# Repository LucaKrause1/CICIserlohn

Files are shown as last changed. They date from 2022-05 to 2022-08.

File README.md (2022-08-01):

# CICIserlohn
Dieses Projekt ist im Zuge der Cross Innovation Class 2022 in der Zusammenarbeit dreier Hochschulen (Fachhochschule Wedel, Akademie für Mode und Design, HafenCity-Universität) und der Kreativgesellschaft Hamburg entstanden. Dabei soll am Ende der Arbeitszeit ein Prototyp entstehen.

Fragestellung: Wie lässt sich das Thema SMART CITY für die Stadtgesellschaft im Wald
| Stadt | Labor Iserlohn erlebbar und greifbar gestalten (z.B. Smart
Gadgets, Sensorik)?

Als Lösung dieser Fragestellung haben wir uns für ein interaktives Stadtmodell entschieden, was, im Gegensatz zu vielen anderen Stadtmodellen auf dem Tisch, an der Wand hängt. Auf dieses Stadtmodell werden Strukturen mit einem Beamer projiziert. Der Nutzer des Modells kann durch verschiedene, mit NFC-Tags versehene, Objekte an einen RFID-Reader halten und dadurch eine Änderung der Strukturen auf dem projizierten Stadtplan hervorrufen.

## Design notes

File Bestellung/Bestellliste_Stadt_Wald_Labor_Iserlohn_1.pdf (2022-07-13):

Bestellliste Stadt Wald Labor Iserlohn 1 | 1

🛒

# Bestellliste Stadt Wald Labor Iserlohn 1

Kosten

Name | Anzahl | Link | Preis pro Stück | Preis
Spule (https://www.notion.so/Spule-8c49362c32854b4bae962a846aa26daf) | 3 | https://www.mouser.de/ProductDetail/Seeed-Studio/106990017?qs=SElPoaY2y5KdLskE1shzqQ%3D%3D | €7.70 | 23.1
Plexiglasröhre 25cm (https://www.notion.so/Plexiglasr-hre-25cm-c4fa1f32a551414896a60412c5162a9e) | 3 | https://www.plattenzuschnitt24.de/Plexiglas-XT-Rohr-3mm-farblos-150-144.html | €15.50 | 46.5
NodeMCU (https://www.notion.so/NodeMCU-fe49acd63b5244f4bf1ca105369e4d74) | 4 | https://www.mouser.de/ProductDetail/Espressif-Systems/ESP32-S2-DevKitM-1?qs=DPoM0jnrROXzO8seOHN%252BOQ%3D%3D (https://www.mouser.de/ProductDetail/Espressif-Systems/ESP32-DevKitC-32E?qs=GedFDFLaBXFpgD0kAZWDrQ%3D%3D) | €9.50 | 38
NFC Reader (https://www.notion.so/NFC-Reader-c93f7a633db04cc8bf8a1b0f69995adc) | 2 | https://www.reichelt.de/entwicklerboards-rfid-modul-nxp-mfrc-522-debo-rfid-rc522-p192147.html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 (https://www.reichelt.de/entwicklerboards-rfid-modul-nxp-mfrc-522-debo-rfid-rc522-p192147.html?PROVID=2788) | €10.40 | 20.8
NFC Tags 10 Stück (https://www.notion.so/NFC-Tags-10-St-ck-2ceb18d98208488e8c25912d936efacc) | 2 | https://www.reichelt.de/rfid-nfc-tags-weiss-10-stueck-berrybase-125450-p313935.html?&trstct=pos_1&nbc=1 (https://www.reichelt.de/rfid-nfc-tags-weiss-10-stueck-berrybase-125450-p313935.html?trstct=pos_1&nbc=1) | €4.60 | 9.2
Filament (https://www.notion.so/Filament-1f2108d9e0b64ece85e25cef391650d0) | 3 | https://www.voelkner.de/products/5806131/Polymaker-70822-PolyTerra-PLA-Filament-PLA-1.75mm-1000g-Weiss-matt-1St..html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 (https://www.voelkner.de/products/5806131/Polymaker-70822-PolyTerra-PLA-Filament-PLA-1.75mm-1000g-Weiss-matt-1St..html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) | €18.90 | 56.7
RaspberryPi (https://www.notion.so/RaspberryPi-6e558a5876fe4d249c60e1b989ea91c8) | 1 | Liegt noch bei dir im Schrank, haben wir letzte Woche drüber geredet | €40.00 | 40
Netzteil (https://www.notion.so/Netzteil-4e05ee1355684bcc99b098a08b8a524c) | 2 | Sollten da auch noch liegen, ansonsten: https://www.reichelt.de/raspberry-pi-netzteil-5-v-2-5-a-micro-usb-schwarz-rasp-nt-25-sw-e-p240934.html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 (https://www.reichelt.de/raspberry-pi-netzteil-5-v-2-5-a-micro-usb-schwarz-rasp-nt-25-sw-e-p240934.html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) | €7.50 | 15
Arcyglaskleber (https://www.notion.so/Arcyglaskleber-7d73b51099e449c5a3fcde43be2412e9) | 1 | https://www.plattenzuschnitt24.de/Acrifix-1R-0192.html | €9.95 | 9.95
LED’s für Baum (https://www.notion.so/LED-s-f-r-Baum-455b00d39e2946deaf79b7cb2db5692d) | 1 | Eigenbestand | €0.00 | 0
Tisch (https://www.notion.so/Tisch-fe3373356d144a98b01e86cf9ac5e2ae) | 1 | | | 0
Base Platte (https://www.notion.so/Base-Platte-695419f74f984da3b0bfcccdbd136a6d) | 1 | | | 0
Beamer (https://www.notion.so/Beamer-f45384da50f442048f5b623bb365f23a) | 0 | https://www.amazon.de/Viewsonic-PA503W-Projektor-Lautsprecher-optischer/dp/B0749NTSCD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 (https://www.amazon.de/Viewsonic-PA503W-Projektor-Lautsprecher-optischer/dp/B0749NTSCD) | €420.00 | 0

Zu den Plexiglasröhren, die Konfiguration sollte so aussehen:

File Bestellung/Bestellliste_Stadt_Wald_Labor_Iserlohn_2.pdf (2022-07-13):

Bestellliste Stadt Wald Labor Iserlohn 2 | 1

🛒

# Bestellliste Stadt Wald Labor Iserlohn 2

Kosten

Name | Anzahl | Link | Preis pro Stück | Preis
Motor (https://www.notion.so/Motor-e24402504231499a8e0da62e9109d887) | 2 | https://www.reichelt.de/entwicklerboards-schrittmotor-inkl-steuerung-uln2003-debo-moto1-p192146.html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 | €5.70 | 11.4
Füße (https://www.notion.so/F-e-257c479b30d344558789728a389d7ed5) | 1

https://www.heimwerkertools.com/moebelbeschlaege/tischbeschlaege/moebelfuessesockelversteller/sockelverstellfuesse/1290/haefele-sockelhoehenversteller-h3930-mit-aufl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 im Endeffekt andere gekauft über Amazon (beinhaltet 4 Füße): (https://www.heimwerkertools.com/moebelbeschlaege/tischbeschlaege/moebelfuesse-sockelversteller/sockelverstellfuesse/1290/haefele-sockelhoehenversteller-h3930-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) https://www.amazon.de/gp/product/B093B3973T/ref=ppx_yo_dt_b_asin_title_o02_s00?ie=UTF8&psc=1

€13.99 | 13.99
SD Karte (https://www.notion.so/SD-Karte-cf0688252be1498da346c247a6cb7903) | 1 | https://www.reichelt.de/microsdhc-speicherkarte-32gb-intenso-class-10-intenso-3413480-p126588.html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 | €5.70 | 5.7

WS2812B 5m

60LEDs/m (https://www.notion.so/WS2812B-5m-60LEDs-m-0d3e1547b6a649f0a9cc99549b60259d) | 1 | https://www.amazon.de/BTF-LIGHTING-WS2812B-300LEDs-Streifen-NichtWasserdicht/dp/B01CDTEJBG/ref=sr_1_6?
| | __mk_de_DE=ÅMÅŽÕÑ&crid=2L99UUTMSW625&keywords=ws2812b&qid=1655209381&sprefix=ws2812b%2Caps%2C107&sr=8-
| | 6 (https://www.amazon.de/BTF-LIGHTING-WS2812B-300LEDs-Streifen-NichtWasserdicht/dp/B01CDTEJBG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) | €41.00 | 41
Netzteil (https://www.notion.so/Netzteil-4e56c5377cda423f8385280d2461815e) | 1 | https://www.reichelt.de/raspberry-pi-netzteil-5-v-2-5-a-micro-usb-schwarz-rasp-nt-25-sw-e-p240934.html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 | €7.50 | 7.5
Motortreiber (https://www.notion.so/Motortreiber-ba87cd8ae5044f4c86f9915cef0a768e) | 3 | https://www.reichelt.de/motortreiber-4-fach-dip-16-l-293-d-ne-p233017.html?&trstct=pos_6&nbc=1 | €3.70 | 11.1
Vibrationsmotoren (https://www.notion.so/Vibrationsmotoren-a66a914f99cd46ddbb9535f4298cdd53) | 3 | https://www.reichelt.de/vibrationsmotor-3-v-150-ma-10-000-u-min-vm-0610-a-3-0-p152129.html?&trstct=pos_0&nbc=1 | €2.20 | 6.6
HDMI Kabel (https://www.notion.so/HDMI-Kabel-cd910cb0324e4462939e0792ff2bdef0) | 1 | https://www.reichelt.de/high-retention-hdmi-kabel-2-0m-hdmi-mmr-2-0muf-p287016.html?&trstct=pos_9&nbc=1 | €7.00 | 7

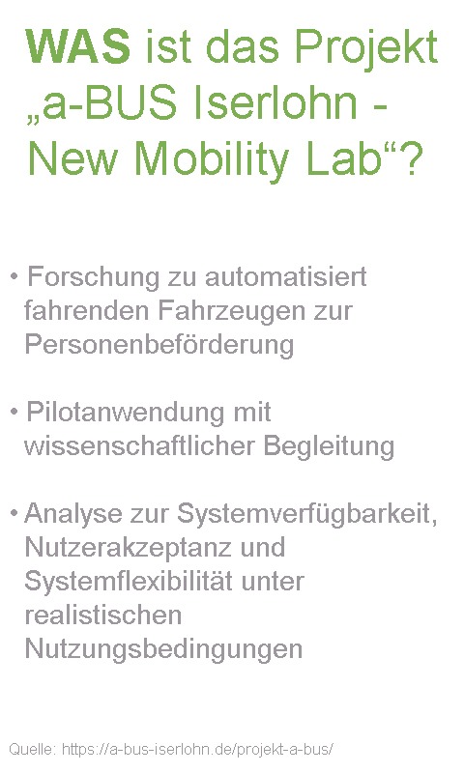
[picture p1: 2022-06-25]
PiScripts/Projection/img/infoabus0.jpg

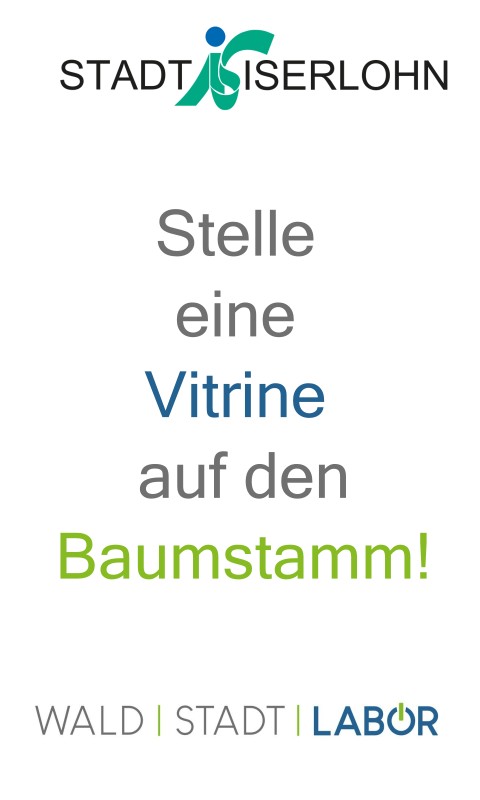
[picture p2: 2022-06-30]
PiScripts/Projection/img/info0.jpg

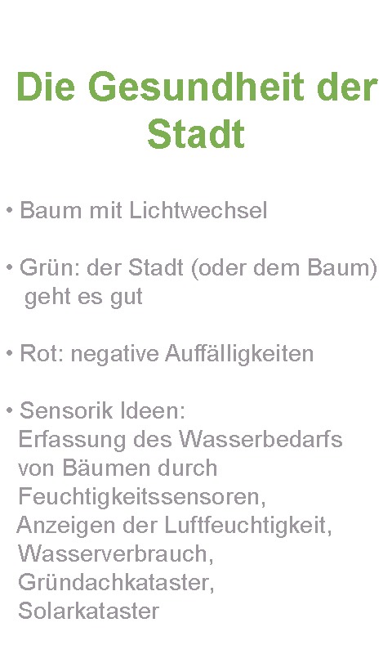
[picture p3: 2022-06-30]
PiScripts/Projection/img/infoTree3.jpg

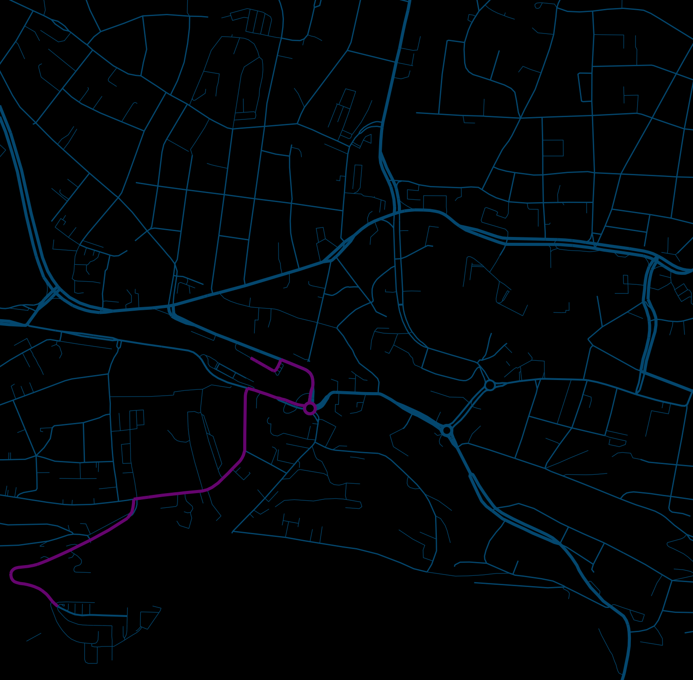
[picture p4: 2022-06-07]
PiScripts/Projection/img/greyBus.png

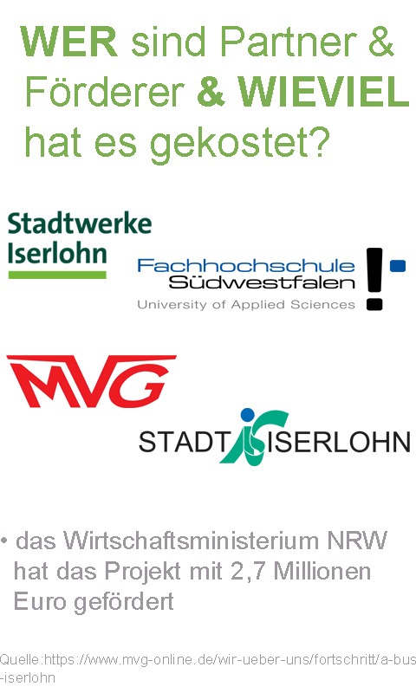
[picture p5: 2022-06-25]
PiScripts/Projection/img/infoabus2.jpg

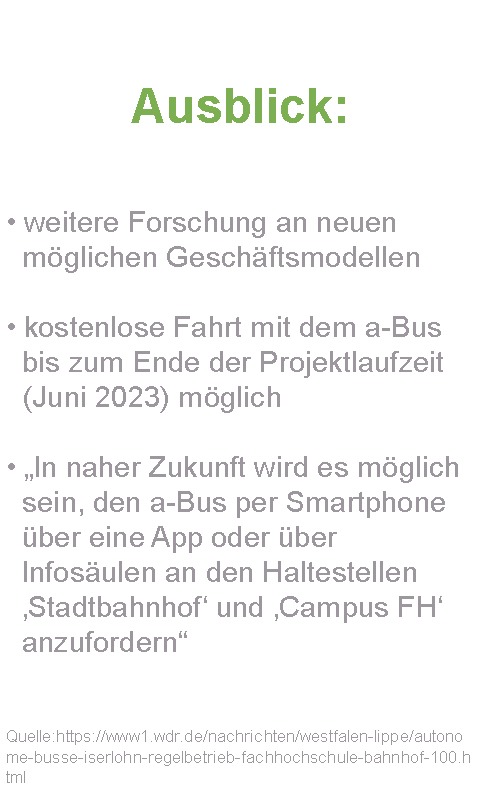
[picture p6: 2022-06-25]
PiScripts/Projection/img/infoabus3.jpg

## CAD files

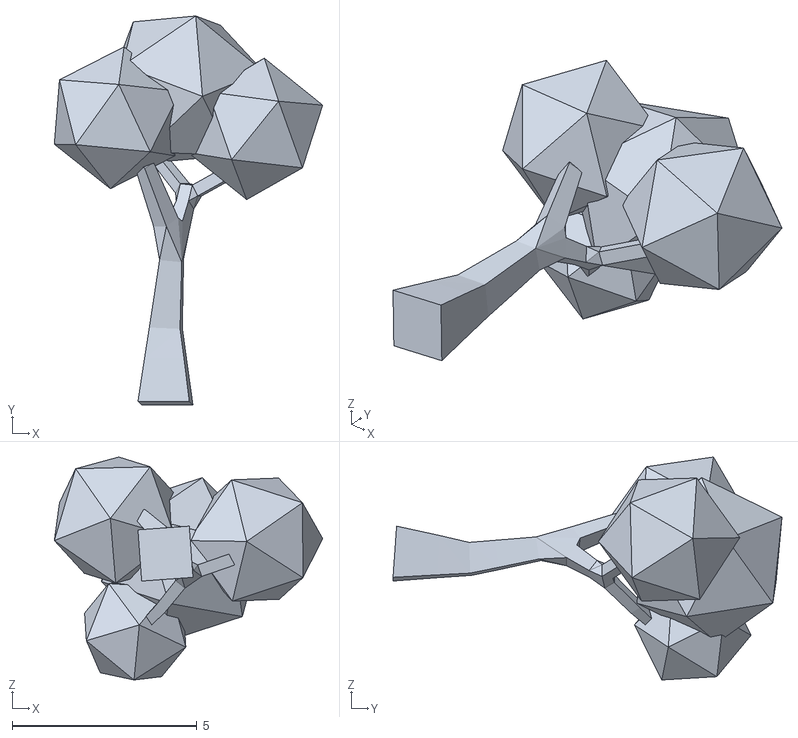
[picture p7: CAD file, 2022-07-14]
3D-Komponenten/Baumv4.obj
7.27 x 10.5 x 6.04

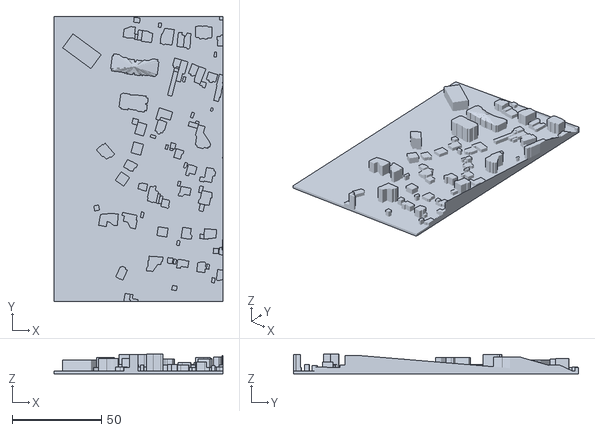
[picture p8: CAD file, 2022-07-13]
3D-Komponenten/Stadtmodell/20.obj
94.9 x 160.0 x 11.0

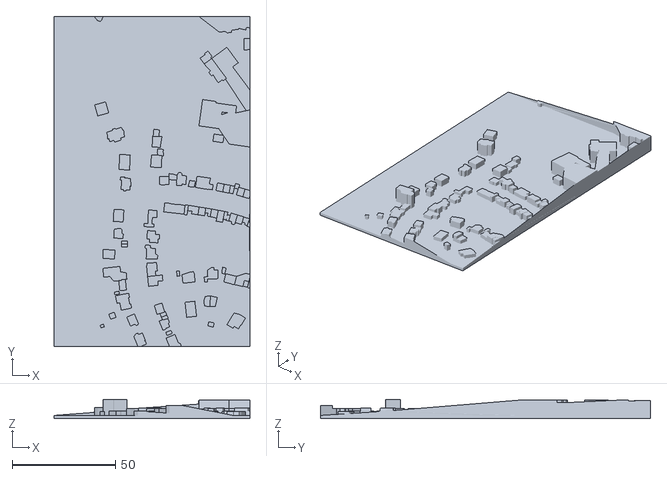
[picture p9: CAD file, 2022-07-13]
3D-Komponenten/Stadtmodell/10.obj
95.0 x 160.1 x 9.40

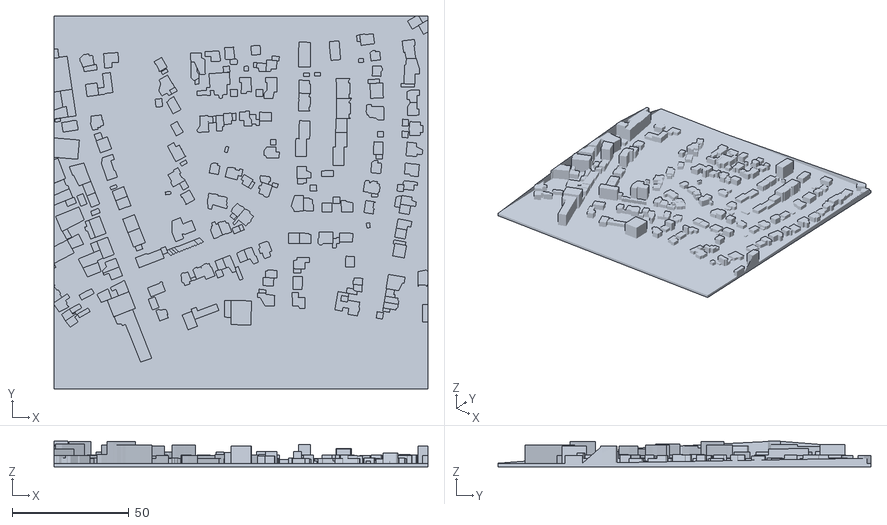
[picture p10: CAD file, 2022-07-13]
3D-Komponenten/Stadtmodell/2.obj
160.1 x 159.5 x 11.1

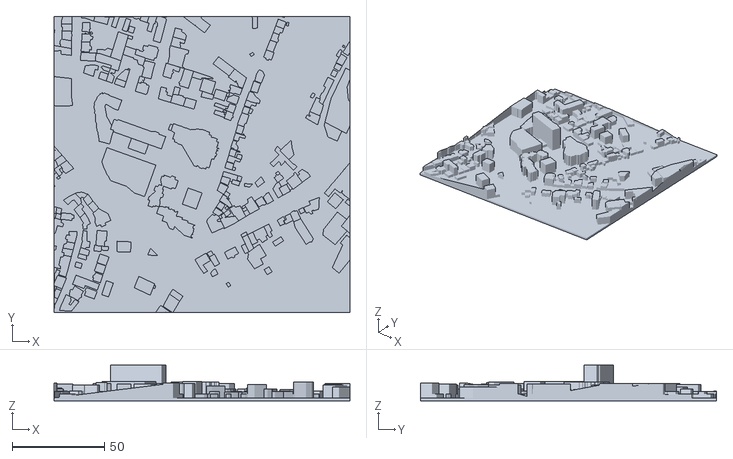
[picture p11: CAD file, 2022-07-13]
3D-Komponenten/Stadtmodell/17.obj
160.1 x 160.1 x 19.3

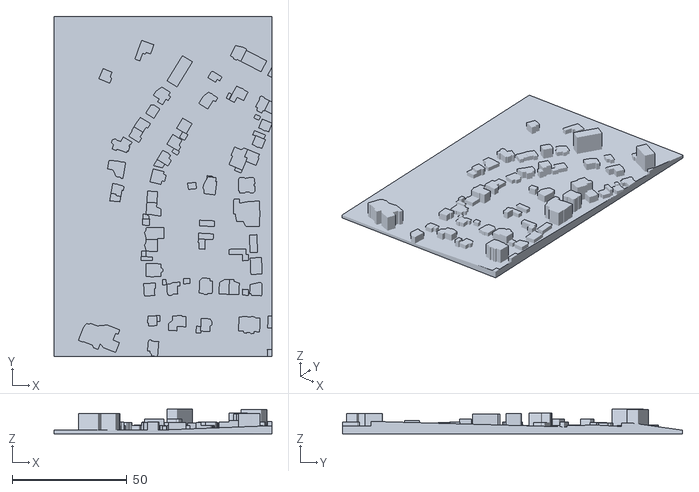
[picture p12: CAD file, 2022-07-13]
3D-Komponenten/Stadtmodell/25.obj
94.9 x 148.1 x 10.7

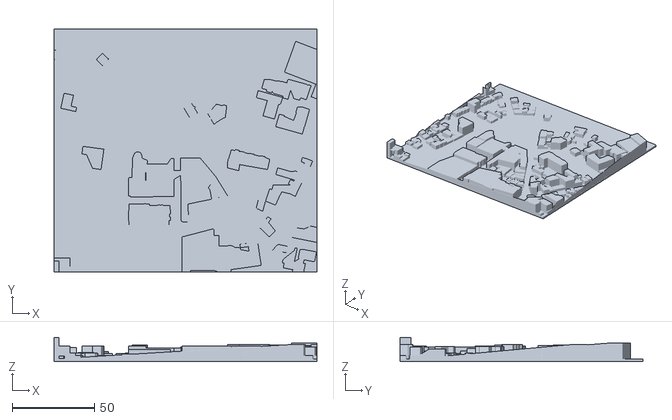
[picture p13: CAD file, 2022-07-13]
3D-Komponenten/Stadtmodell/23.obj
160.1 x 148.1 x 14.6

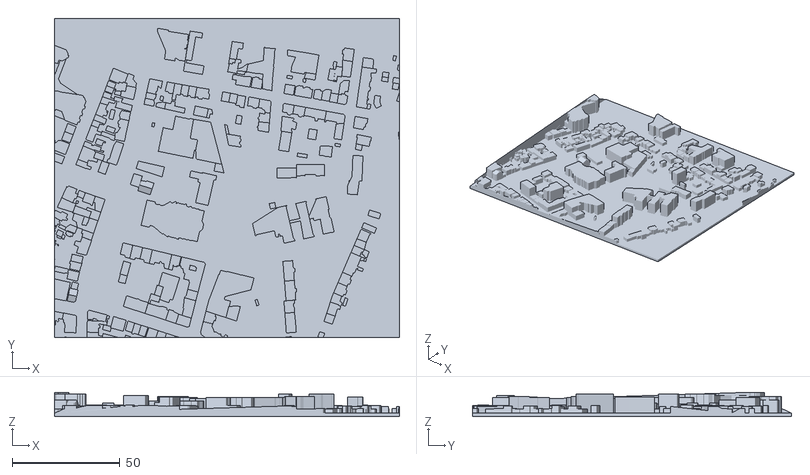
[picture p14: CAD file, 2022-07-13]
3D-Komponenten/Stadtmodell/22.obj
160.0 x 148.1 x 11.3

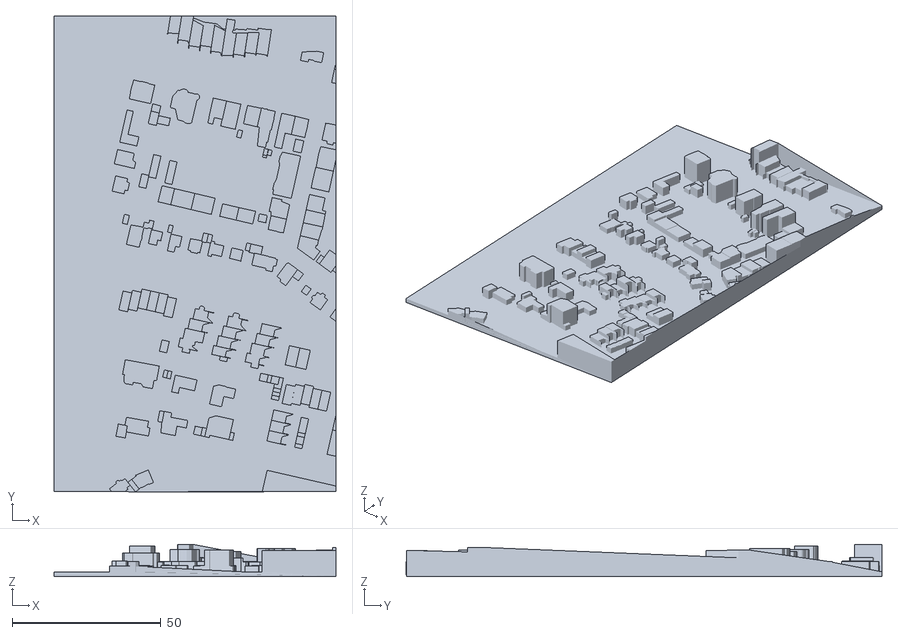
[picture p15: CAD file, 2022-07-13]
3D-Komponenten/Stadtmodell/15.obj
94.9 x 160.1 x 10.8

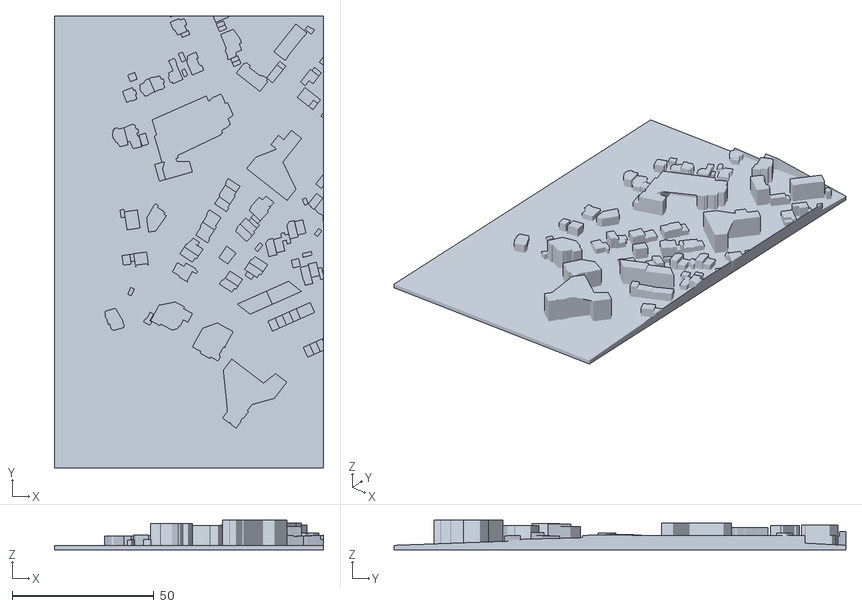
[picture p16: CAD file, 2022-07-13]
3D-Komponenten/Stadtmodell/5.obj
94.9 x 159.5 x 10.5

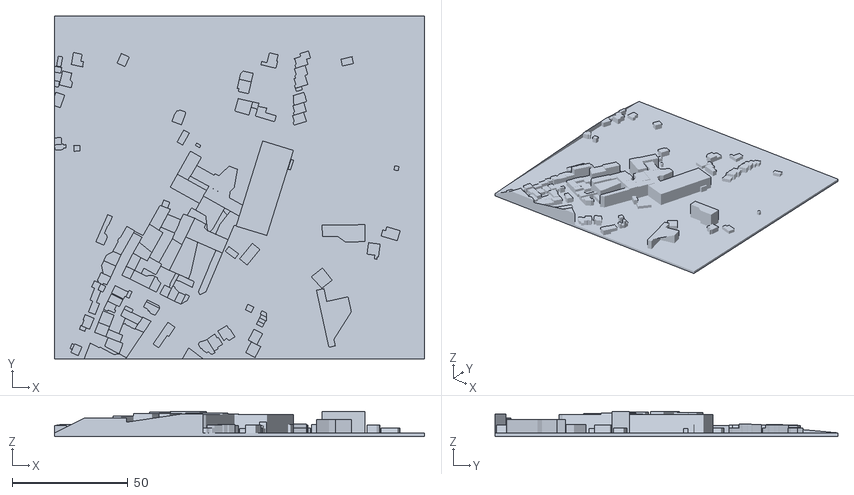
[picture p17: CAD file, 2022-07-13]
3D-Komponenten/Stadtmodell/21.obj
159.8 x 148.0 x 10.8

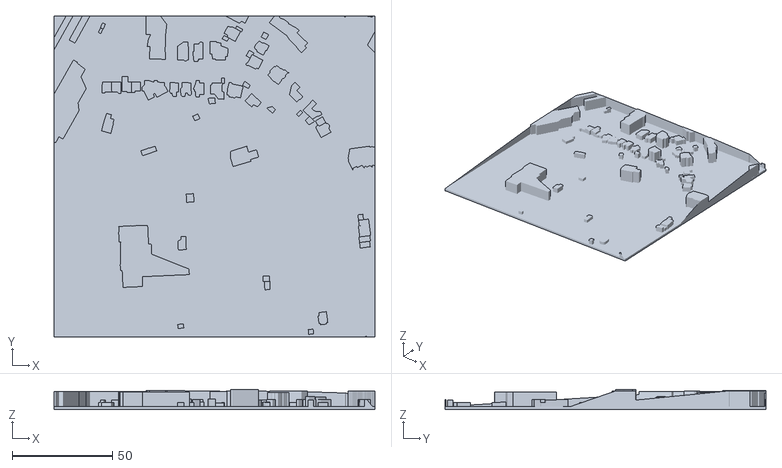
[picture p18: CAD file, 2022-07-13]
3D-Komponenten/Stadtmodell/7.obj
160.0 x 160.0 x 10.2

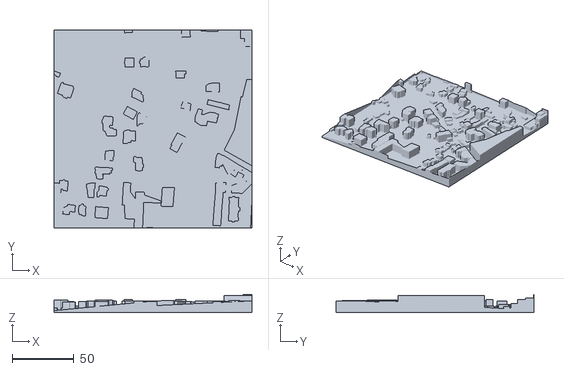
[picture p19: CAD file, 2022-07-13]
3D-Komponenten/Stadtmodell/19.obj
160.1 x 160.0 x 14.6

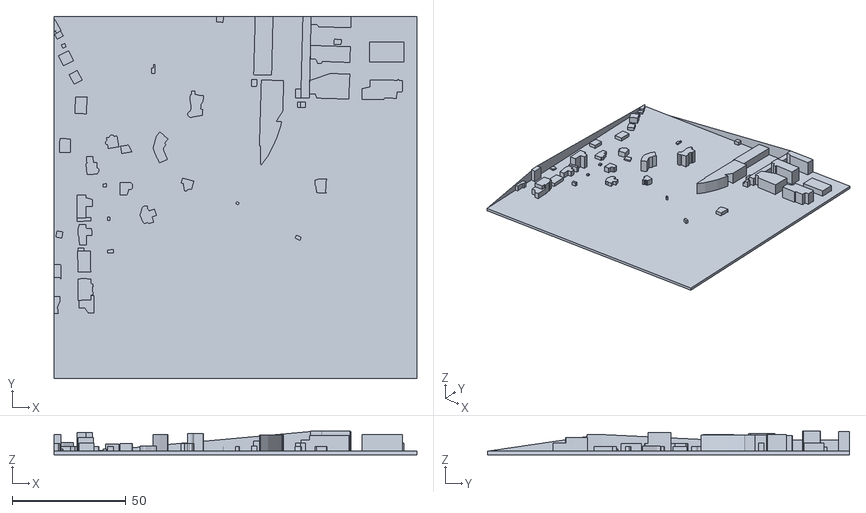
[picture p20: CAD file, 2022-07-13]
3D-Komponenten/Stadtmodell/1.obj
159.8 x 159.5 x 10.4

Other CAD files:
3D-Komponenten/Stadtmodell/14.obj
3D-Komponenten/Stadtmodell/13.obj
3D-Komponenten/Stadtmodell/12.obj
3D-Komponenten/Stadtmodell/6.obj
3D-Komponenten/28BYJ_48_5V_Stepper Motor.f3d
3D-Komponenten/Basis_Vitrine.f3d
3D-Komponenten/BaumDruck.f3d
3D-Komponenten/DeckelABUS.f3z
3D-Komponenten/FlaecheStadtmodell.f3d
3D-Komponenten/RFIDReader.f3d
3D-Komponenten/Stadtmodell/11.obj
3D-Komponenten/Stadtmodell/16.obj
3D-Komponenten/Stadtmodell/18.obj
3D-Komponenten/Stadtmodell/24.obj
3D-Komponenten/Stadtmodell/3.obj
3D-Komponenten/Stadtmodell/4.obj
3D-Komponenten/Stadtmodell/8.obj
3D-Komponenten/Stadtmodell/9.obj
3D-Komponenten/TischEinsatz.f3z

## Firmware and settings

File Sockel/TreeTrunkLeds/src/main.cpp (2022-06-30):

#include <Arduino.h>

#include <Adafruit_NeoPixel.h>

#define PIN 26
#define NUMPIXELS 150

Adafruit_NeoPixel pixels(NUMPIXELS, PIN, NEO_GRB + NEO_KHZ800);

#define DELAYVAL 20

void setup() {
  delay(100);
  pixels.begin();
}

void displayAll(int r, int g) {
  for (int pixel = 0; pixel < NUMPIXELS; pixel++) {
    pixels.setPixelColor(pixel, pixels.Color(r, g, 0));
  }
  pixels.show();
  delay(DELAYVAL);
}

void loop() {
  int r = 0;
  int g = 255;
  while (r < 255) {
    displayAll(r, g);
    r++;
  }
  // r 255 g 255
  while (r > 0) {
    displayAll(r, g);
    r--;
  }
  // r 0 g 255
  for(int i=0; i<255; i++){
    delay(DELAYVAL);
  }
}

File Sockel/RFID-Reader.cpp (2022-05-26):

//www.elegoo.com
//2016.12.09
#include <SPI.h>
#include <MFRC522.h>
#include <string>

#include <ESP8266WiFi.h>
#include <WiFi.h>

#define RST_PIN   16     // Configurable, see typical pin layout above
#define SS_PIN    5    // Configurable, see typical pin layout above

#define NUMBER_TAGS 6
#define DIFFERENT_TAGS 2
MFRC522 mfrc522(SS_PIN, RST_PIN);   // Create MFRC522 instance

const char* ssid = "cic";
const char* password =  "cic";

/*
 * Vorherige Schlüssel aller 12:
 * 1. 04 4C 77 15 39 6C 80
 * 2. 04 23 B7 14 39 6C 80
 * 3. 04 BC EC 14 39 6C 80
 * 4. 04 B3 33 15 39 6C 80
 * 5. 04 95 FA 14 39 6C 80
 * 6. 04 7B C5 14 39 6C 80
 * 7. 04 09 8D 15 39 6C 80
 * 8. 04 59 E7 14 39 6C 80
 * 9. 04 52 A4 15 39 6C 80
 * 10. 04 DE F5 05 49 6C 80
 * 11. 04 36 E7 14 39 6C 80
 * 12. 04 F3 74 15 39 6C 80
 */

MFRC522::MIFARE_Key key;

std::string UIDs[DIFFERENT_TAGS][NUMBER_TAGS] = {
  {//A-Bus
 "04 09 8D 15 39 6C 80",
 "04 59 E7 14 39 6C 80",
 "04 52 A4 15 39 6C 80",
 "04 DE F5 05 49 6C 80",
 "04 36 E7 14 39 6C 80",
 "04 F3 74 15 39 6C 80"},
  {//Baum
 "04 4C 77 15 39 6C 80",
 "04 23 B7 14 39 6C 80",
 "04 BC EC 14 39 6C 80",
 "04 B3 33 15 39 6C 80",
 "04 95 FA 14 39 6C 80",
 "04 7B C5 14 39 6C 80"}
};

void setup() {
  Serial.begin(9600);  // Initialize serial communications with the PC
  while (!Serial);     // Do nothing if no serial port is opened (added for Arduinos based on ATMEGA32U4)
  SPI.begin();         // Init SPI bus
  mfrc522.PCD_Init();  // Init MFRC522 card
  Serial.println(F("Warning: this example overwrites the UID of your UID changeable card, use with care!"));
  
  // Prepare key - all keys are set to FFFFFFFFFFFFh at chip delivery from the factory.
  for (byte i = 0; i < 6; i++) {
    key.keyByte[i] = 0xFF;
  }

  //WIFI
  WiFi.begin(ssid, password);
 
  while (WiFi.status() != WL_CONNECTED) {
    delay(1000);
    Serial.println("Ich verbinde mich mit dem Internet...");
  }
  Serial.println("Ich bin mit dem Internet verbunden!");
}

/**
 * inspiriert von:
 * https://www.c-plusplus.net/forum/topic/327301/byte-zu-hexstring/11
 */
void hexString(char * bytes, std::size_t bytesLength, char* dest){
  static char const lookup[] = "0123456789ABCDEF";

  for (std::size_t i = 0; i < bytesLength; i++){
    dest[3*i  ] = lookup[ bytes[i] >> 4  ];
    dest[3*i+1] = lookup[ bytes[i] & 0xF ];
    if (i != bytesLength - 1) {
      dest[3*i+2] = ' ';
    }
  }
}


void loop() {
  // Look for new cards, and select one if present
  if ( ! mfrc522.PICC_IsNewCardPresent() || ! mfrc522.PICC_ReadCardSerial() ) {
    delay(50);
    return;
  }
  // Now a card is selected. The UID and SAK is in mfrc522.uid.
  
  char b[mfrc522.uid.size] = {};
  byte size = mfrc522.uid.size * 2 + mfrc522.uid.size - 1;
  for (byte i = 0; i < mfrc522.uid.size; i++) {    
    b[i] = mfrc522.uid.uidByte[i];
    Serial.print(mfrc522.uid.uidByte[i] < 0x10 ? " 0" : " ");
    Serial.print(mfrc522.uid.uidByte[i], HEX);
  }
  Serial.println();

  //je zwei zeichen + leerzeichen (ohne letzte Zahl) + Ende: null
  char dest[3*sizeof b];

  hexString(b, sizeof b, dest);
  dest[3*sizeof b - 1] = '\0';
  //Serial.println(dest);

  //default = 0 -> keine gültige Vitrine
  byte showcase = 0;
  std::string s(dest);

  for(int i = 0; i < DIFFERENT_TAGS; i++) {
    for(int j = 0; j < sizeof NUMBER_TAGS; j++) {
      if (s == UIDs[i][j]) {
        showcase = i + 1;
      }
    }
  }
  
  Serial.println(showcase);
  //TODO: Zahl weitergeben!!! -> über WLAN oder Kabel
  
  
  delay(1000);
}

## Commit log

2022-05-26 MQTT und RFID-Reader verbunden, jetzt noch testen (:
2022-06-09 Bus fährt jetzt auf dem Bild eine gerade Linie; Winkelberechnung und Mittelung über die letzten 5 Werte
2022-06-09 First working version of MainLogic with switching
2022-06-09 Koordinaten der Busroute hochgeladen
2022-06-09 Fixes bug that tags are not recognized and raised threshold for none.
    [main.cpp]
2022-06-11 First version of calibration script
2022-06-27 Adds calibration to MainLogic
2022-06-30 Adds calibration for info plane
2022-07-13 3d-komponenten hinzugefuegt
    [Basis.stl, BasisAbus.stl, BaumDruck.stl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]
2022-07-13 weitere 3D-Komponenten
    [1.obj, 10.obj, 11.obj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]
2022-07-13 Modell geloescht und Bestellung aktualisiert.
    [18fixobj.obj]
2022-07-14 3D-Daten aktualisiert nach f3d und f3z Dateien
    [28BYJ_48_5V_Stepper Motor.f3d, Basis.stl, BasisAbus.stl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]
2022-07-14 Transformationsfehler, der vom Pi nicht hochgeladen wurde, jetzt hier eingetragen
